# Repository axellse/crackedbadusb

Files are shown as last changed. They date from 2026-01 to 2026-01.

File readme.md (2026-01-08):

# scriptstick
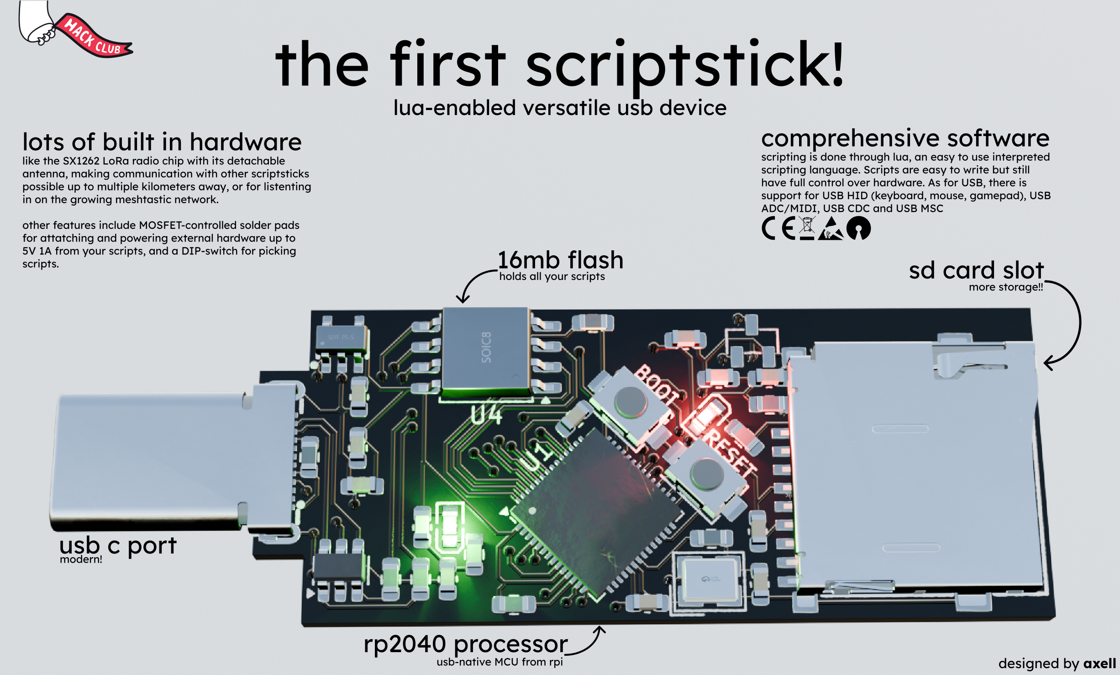
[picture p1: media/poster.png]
image of scriptstick


The scriptstick is a versatile scripting device in the form of a usb flash drive. It can be used for BadUsb, automation and meshtastic. The firmware writen in go, and custom scripts are written in lua. 

The scriptstick project is sponsored by [Hack club](https://hack.club).

## blueprint approval stuff
here is the schematic for the project:

bild

here is the pcb inside of kicad:

bild

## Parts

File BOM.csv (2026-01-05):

Name | Quantity | Unit cost (SEK) | Variant | Manufacturer/seller | Cost (SEK) | Link | Comment
USB C to A adapter | 1 | 22,17 | Blue A to C | Elough Store/Aliexpress | 22,17 | Link | Required as my PC only has USB A and not C
Components | 3 | 134,67 | N/A | LCSC | 404,01 | N/A (Private shopping cart) | See production/lcsc_bom.csv in the git repo
LCSC Shipping Fee | N/A | N/A | Global Direct Standard Line | LCSC | 91,75 | N/A
PCBs | 10 | 4,73 | Black 2-layer | JLCPCB | 47,3 | N/A (Private shopping cart) | See production/gerber.zip in the git repo.
PCB Stencil | 1 | 108,42 | Top+Bottom on same stencil | JLCPCB | 108,42 | N/A (Private shopping cart) | I assemble myself to minimize costs
JLCPCB Shipping Fee | N/A | N/A | Global Direct Standard Line | JLCPCB | 179,73 | N/A
Solder paste | 1 | 72,86 | HXP-603-10g-1PCS | PXAN Top Tier Tool Store/Aliexpress | 72,86 | Link | First time using solder paste and stencil
Aliexpress Shipping Fee | N/A | N/A | Choice shipping (cheapest) | Aliexpress | 18,68 | N/A
Total (SEK) | N/A | N/A | N/A | N/A | 944,92 | N/A | Note that Swedish 25% sales tax is included in all prices
Total (USD): 102.94$
Total (USD, excluding what im putting in): 100$ |  |  |  |  |  |  | I went overbudget by 2 dollars which im paying from my own pocket

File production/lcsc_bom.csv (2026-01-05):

Designator | Footprint | Quantity | Value | LCSC Part #
BOOT1, RESET1 | SW-SMD_L3.9-W3.0-P4.45 | 2 | TS-1088-AR02016 | C720477
C1, C2 | 603 | 2 | 10u | C19702
C10, C11, C13, C6, C8, C9 | 603 | 6 | 100n | C1591
C3, C7 | 603 | 2 | 1u | C15849
C4, C5 | 603 | 2 | 15p | C1644
CARD2 | TF-SMD_TF-01A | 1 | TF-01A | C91145
LED_PWR1, LED_PWR2 | LED0603-RD_GREEN | 2 | XL-1608UGC-04 | C965804
Q1 | SOT-23-3_L2.9-W1.3-P1.90-LS2.4-BR | 1 | AO3400A_C347475 | C347475
Q2 | SOT-25_L3.0-W1.6-P0.95-LS2.8-TL | 1 | XC6220B331MR-G | C86534
R1 | 603 | 1 | 5.1K | C2907044
R10, R9 | 603 | 2 | 150 | C114608
R2, R8 | 603 | 2 | 10K | C98220
R3, R5 | 603 | 2 | 1k | C22548
R6, R7 | 603 | 2 | 27.4 | C5126244
U1 | QFN-56-1EP_7x7mm_P0.4mm_EP3.2x3.2mm | 1 | RP2040 | C2040
U2 | SW-SMD_8P-L6.7-W5.4-P1.27-LS8.4 | 1 | DSHP04TSGER_C3293144 | C3293144
U3 | SOT-23-6 | 1 | USBLC6-2SC6 | C7519
U4 | SOIC-8_5.23x5.23mm_P1.27mm | 1 | W25Q128JVS | C97521
U5 | CRYSTAL-SMD_4P-L3.2-W2.5-BL | 1 | ABM8-272-T3_C20625731 | C20625731
U8 | Ai-Thinker-Ra-01-LoRa | 1 | Ai-Thinker-Ra-02 | C90039
USB2 | USB-C-SMD_U261-121N-4BS2S | 1 | U261-121N-4BS2S | C2879827

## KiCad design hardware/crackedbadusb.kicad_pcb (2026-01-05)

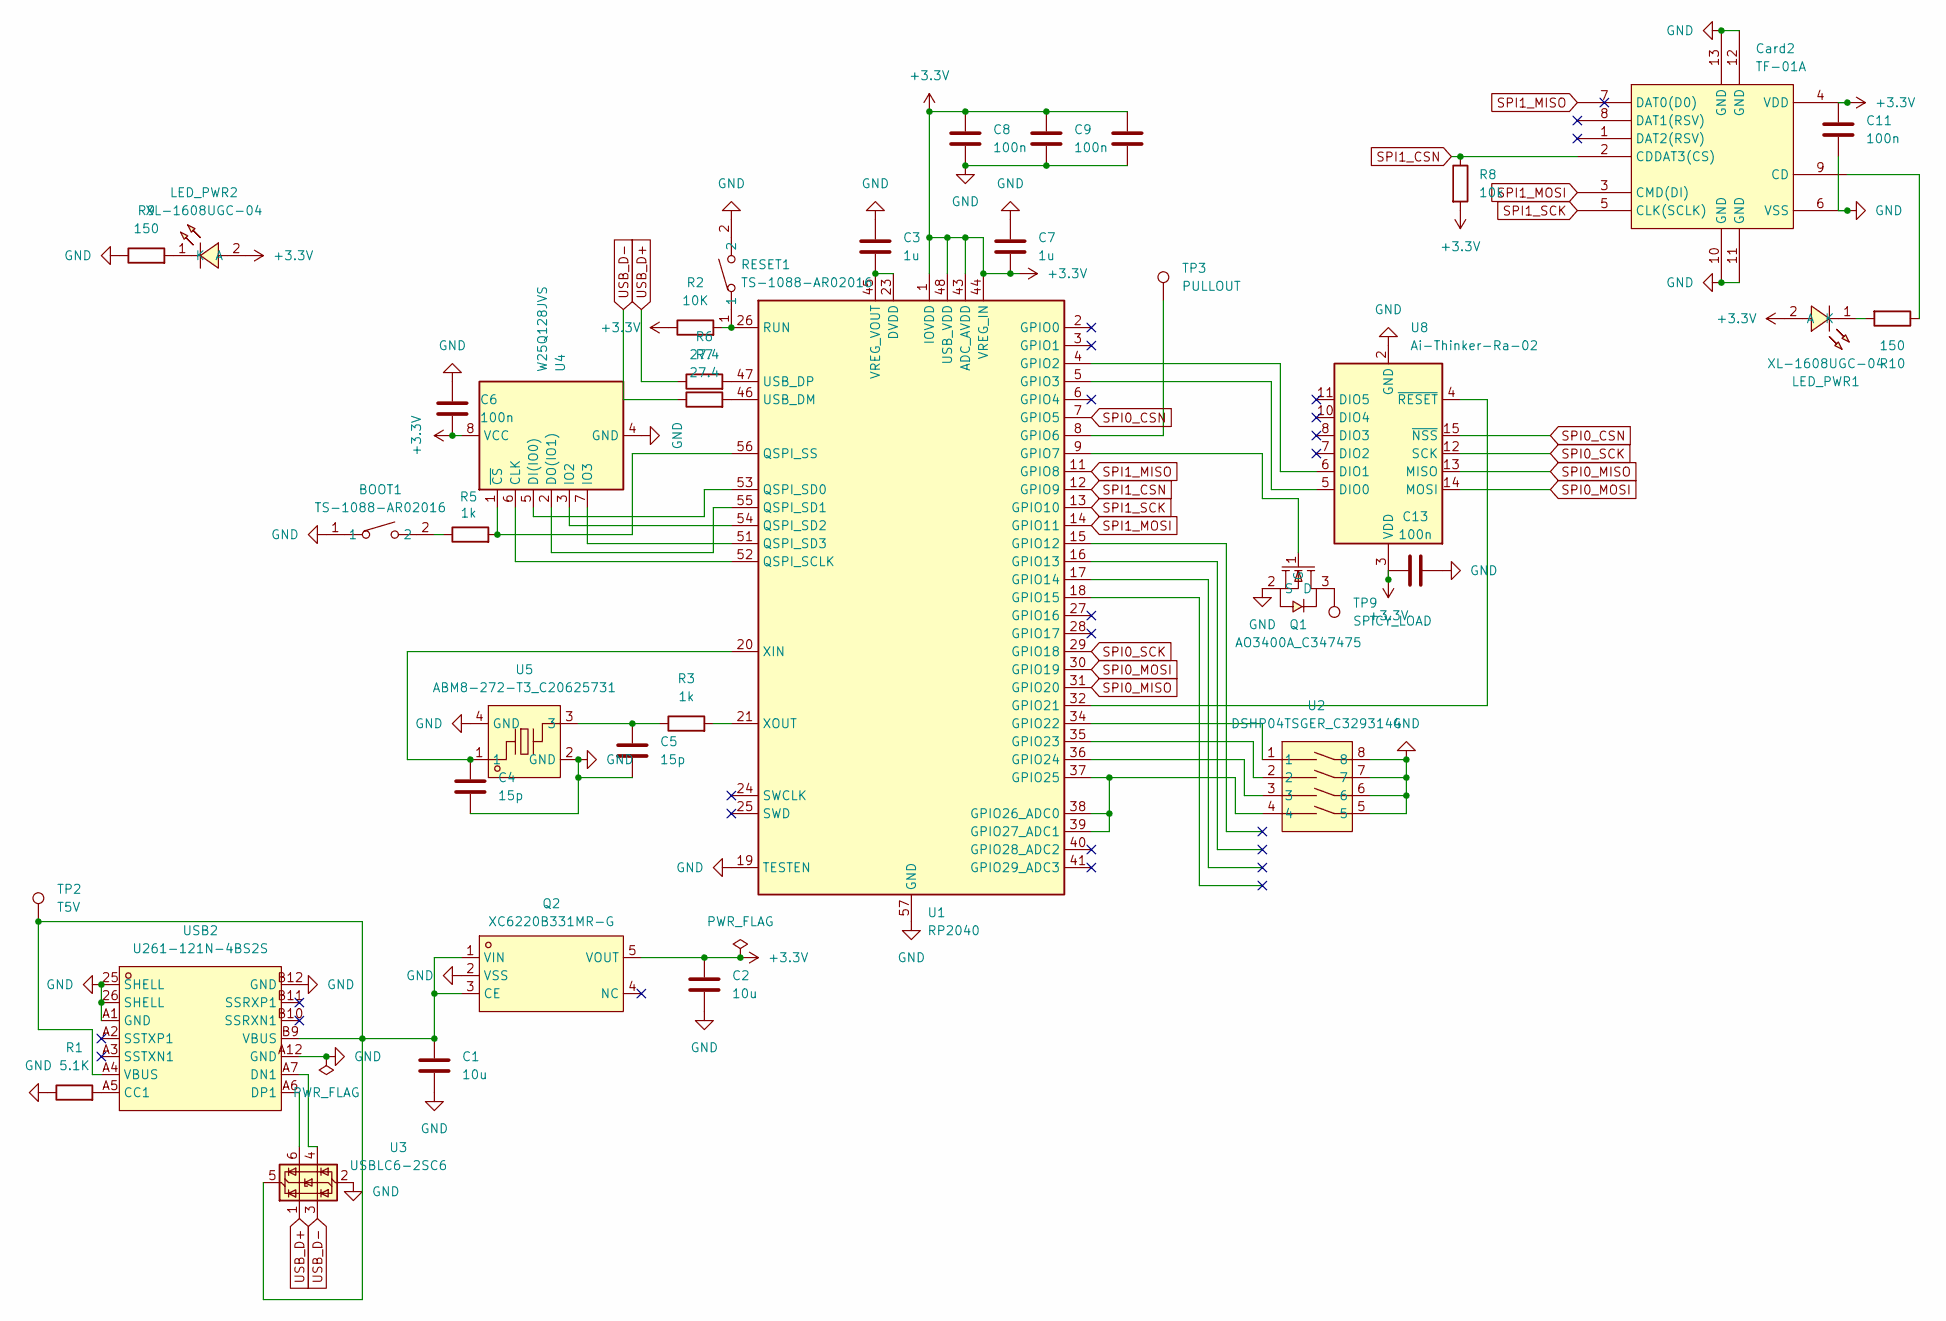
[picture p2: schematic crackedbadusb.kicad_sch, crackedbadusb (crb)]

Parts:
BOOT1: TS-1088-AR02016; SW-SMD_L3.9-W3.0-P4.45; LCSC Part C720477
C1, C2: 10u; C_0603_1608Metric
C3, C7: 1u; C_0603_1608Metric
C4, C5: 15p; C_0603_1608Metric
C6, C8, C9, C10, C11, C13: 100n; C_0603_1608Metric
Card2: TF-01A; TF-SMD_TF-01A; LCSC Part C91145
LED_PWR1, LED_PWR2: XL-1608UGC-04; LED0603-RD_GREEN; LCSC Part C965804
Q1: AO3400A_C347475; SOT-23-3_L2.9-W1.3-P1.90-LS2.4-BR; LCSC Part C347475
Q2: XC6220B331MR-G; SOT-25_L3.0-W1.6-P0.95-LS2.8-TL; LCSC Part C86534
R1: 5.1K; R_0603_1608Metric
R2: 10K; R_0603_1608Metric
R3, R5: 1k; R_0603_1608Metric
R6, R7: 27.4; R_0603_1608Metric
R8: 10k; R_0603_1608Metric
R9, R10: 150; R_0603_1608Metric
RESET1: TS-1088-AR02016; SW-SMD_L3.9-W3.0-P4.45; LCSC Part C720477
TP2: T5V; TestPoint_Pad_D2.0mm
TP3: PULLOUT; TestPoint_Pad_D2.5mm
TP9: SPICY_LOAD; TestPoint_Pad_D2.5mm
U1: RP2040; QFN-56-1EP_7x7mm_P0.4mm_EP3.2x3.2mm
U2: DSHP04TSGER_C3293144; SW-SMD_8P-L6.7-W5.4-P1.27-LS8.4; LCSC Part C3293144
U3: USBLC6-2SC6; SOT-23-6
U4: W25Q128JVS; SOIC-8_5.23x5.23mm_P1.27mm
U5: ABM8-272-T3_C20625731; CRYSTAL-SMD_4P-L3.2-W2.5-BL; LCSC Part C20625731
U8: Ai-Thinker-Ra-02; Ai-Thinker-Ra-01-LoRa
USB2: U261-121N-4BS2S; USB-C-SMD_U261-121N-4BS2S; LCSC Part C2879827

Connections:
+3.3V: C2.1, C6.2, C7.2, C8.1, C9.1, C10.1, C11.1, C13.1, Card2.4 (VDD), LED_PWR1.2 (A), LED_PWR2.2 (A), Q2.5 (VOUT), R2.1, R8.2, U1.1 (IOVDD), U1.10 (IOVDD), U1.22 (IOVDD), U1.33 (IOVDD), U1.42 (IOVDD), U1.43 (ADC_AVDD), U1.44 (VREG_IN), U1.48 (USB_VDD), U1.49 (IOVDD), U4.8 (VCC), U8.3 (VDD)
GND: BOOT1.1, C1.2, C2.2, C3.1, C4.2, C5.2, C6.1, C7.1, C8.2, C9.2, C10.2, C11.2, C13.2, Card2.6 (VSS), Card2.10 (GND), Card2.11 (GND), Card2.12 (GND), Card2.13 (GND), Q1.2 (S), Q2.2 (VSS), R1.1, R9.1, RESET1.2, U1.19 (TESTEN), U1.57 (GND), U2.5, U2.6, U2.7, U2.8, U3.2 (GND), U4.4 (GND), U5.2 (GND), U5.4 (GND), U8.1 (GND), U8.2 (GND), U8.9 (GND), U8.16 (GND), USB2.25 (SHELL), USB2.26 (SHELL), USB2.A1 (GND), USB2.A12 (GND), USB2.B12 (GND)
unnamed: BOOT1.2, R5.1
unnamed: C5.1, R3.1, U5.3
unnamed: Card2.9 (CD), R10.1
unnamed: LED_PWR1.1 (K), R10.2
unnamed: LED_PWR2.1 (K), R9.2
unnamed: Q1.3 (D), TP9.1
unnamed: Q1.1 (G), U1.9 (GPIO7)
unnamed: C1.1, Q2.1 (VIN), Q2.3 (CE), TP2.1, U3.5 (VBUS), USB2.A4 (VBUS), USB2.B9 (VBUS)
unnamed: U1.4 (GPIO2), U8.6 (DIO1)
unnamed: U1.5 (GPIO3), U8.5 (DIO0)
unnamed: TP3.1, U1.8 (GPIO6)
unnamed: U1.32 (GPIO21), U8.4 (~RESET)
unnamed: U1.34 (GPIO22), U2.1
unnamed: U1.35 (GPIO23), U2.2
unnamed: U1.36 (GPIO24), U2.3
unnamed: U1.37 (GPIO25), U1.38 (GPIO26_ADC0), U1.39 (GPIO27_ADC1), U2.4
unnamed: U1.52 (QSPI_SCLK), U4.6 (CLK)
unnamed: U1.53 (QSPI_SD0), U4.5 (DI(IO0))
unnamed: U1.55 (QSPI_SD1), U4.2 (DO(IO1))
unnamed: U1.54 (QSPI_SD2), U4.3 (IO2)
unnamed: U1.51 (QSPI_SD3), U4.7 (IO3)
unnamed: R5.2, U1.56 (QSPI_SS), U4.1 (~CS)
unnamed: R2.2, RESET1.1, U1.26 (RUN)
unnamed: R7.2, U1.46 (USB_DM)
unnamed: R6.2, U1.47 (USB_DP)
unnamed: C3.2, U1.23 (DVDD), U1.45 (VREG_VOUT), U1.50 (DVDD)
unnamed: C4.1, U1.20 (XIN), U5.1
unnamed: R3.2, U1.21 (XOUT)
unnamed: R1.2, USB2.A5 (CC1)
unnamed: U3.4 (I/O2), USB2.A7 (DN1)
unnamed: U3.6 (I/O1), USB2.A6 (DP1)
SPI0_CSN: U1.7 (GPIO5), U8.15 (~NSS)
SPI0_MISO: U1.31 (GPIO20), U8.13 (MISO)
SPI0_MOSI: U1.30 (GPIO19), U8.14 (MOSI)
SPI0_SCK: U1.29 (GPIO18), U8.12 (SCK)
SPI1_CSN: Card2.2 (CDDAT3(CS)), R8.1, U1.12 (GPIO9)
SPI1_MISO: Card2.7 (DAT0(D0)), U1.11 (GPIO8)
SPI1_MOSI: Card2.3 (CMD(DI)), U1.14 (GPIO11)
SPI1_SCK: Card2.5 (CLK(SCLK)), U1.13 (GPIO10)
USB_D+: R6.1, U3.1 (I/O1)
USB_D-: R7.1, U3.3 (I/O2)

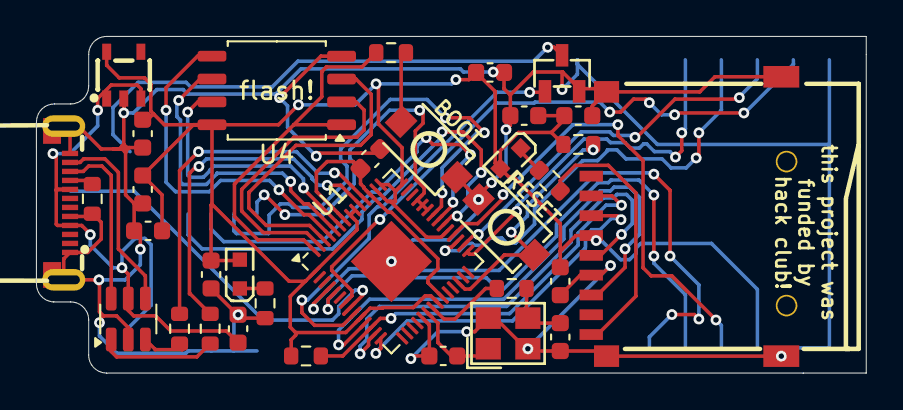
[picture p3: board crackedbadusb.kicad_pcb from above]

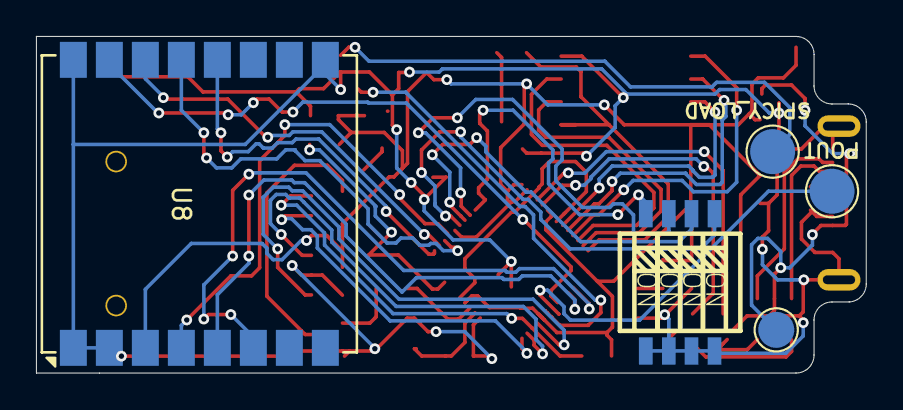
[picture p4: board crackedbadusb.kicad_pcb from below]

Board: 2 copper layers, 46.1 x 18.7 mm, 38 parts (5 on the bottom side), 43 nets.

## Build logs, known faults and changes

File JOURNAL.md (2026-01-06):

<!--
  ===================    !!READ THIS NOTICE!!   ====================
  DO NOT edit this file manually. Your changes WILL BE OVERWRITTEN!
  This journal is auto generated and updated by Hack Club Blueprint.
  To edit this file, please edit your journal entries on Blueprint.
  ==================================================================
-->

## 10/20/2025 6 PM - Initial research  

Ive done some research and sadly i will not be able to have the stick act as a display due to the usb graphics controllers not being available to hobbyists. I will still be able to have it act as a mass media device and some other stuff though. I have decided on the rp2040 for its native usb support.
Skärmbild 2025-10-20 180054.png  

## 10/20/2025 10 PM - began working on schematic  

Im very new to pcb/circuit design, but ive started working on the schematic for the board. Right now i only have the usb c plug, a voltage regulator for the microcontroller, and a diode array IC for ESD protection.

  

## 10/21/2025 - Finished basic schematic for RP2040  



Ive now finished the circuit for getting the RP2040 up and running. I have the following components laid out right now:
- The rp2040 (ofc)
- A crystal oscillator for the clock
- A 16mb flash chip
- The usb c connector
- A diode array ic for esd protection on the usb c connector
- A 3.3v voltage regulator as to not magic smoke the rp2040
- Reset and boot buttons
- Debug connector
- and a bunch of passives

Next up is actually making it do something!

P.S, if you're making something with an RP2040, check out [Hardware design with RP2040](https://datasheets.raspberrypi.com/rp2040/hardware-design-with-rp2040.pdf) and the datasheets, they are both great resources!  

## 10/31/2025 12:06 AM - Picking the right radio chip  

One of the major features of this badusb that sets it apart is the integrated lora radio. I initially wanted to use the SX1262 chip directly as its pretty new and has a good power efficiency. It wouldn't be *that* hard to use the chip directly, but RF is pretty much black magic to me and making sure i don't get a bunch of interference to the rp2040 that's right next to it is not something i would be able to pull of with my current skills.

The other route is to use an off-the-shelf module that does all the hard RF design for you. These modules also have a nice little metal faraday cage thingy to minimize interference further.

original

While SX1262 modules exists, i have pretty tight dimensions constraints and i couldn't find any that would fit, so i decided to go with an SX1278 module instead which are more common. Specifically the Ai-Thinker RA-02 (not sure how a lora module has even remotely anything to do with ai), which i have used in projects before  

## 10/31/2025 12:36 AM - Schematic done (almost)  

Added the dip switch, radio chip, the pull out sensor and a neopixel. Theres not much else but i remember needing another button i just forgot what i would need it for.

bild

## 11/5/2025 - Schematic finally done  

Now the schematic is finally done and its time to start working on the PCB. I'm still not happy about using a module for the LoRa radio, but i will have to change that in another revision. 

I added:
- SD card reader
- more leds (yay)
- Test points
- looked through everything (found that my usb data lines were flipped, very glad i catched that)

bild
